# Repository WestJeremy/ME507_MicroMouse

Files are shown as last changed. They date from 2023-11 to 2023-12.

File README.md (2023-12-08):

# ME507_MicroMouse
This repository contains files for a custom PCB and c based code for a micromouse project for ME507 at Cal Poly SLO. This README.md file covers the task diagram and finite state implimentation used for this project.

## TASK DIAGRAM

## FINITE STATE MACHINES
### FloodFill Task
The following finite state machine is implimented for the task that impliments the floodfill algorithm for maze solving. The task begins in an idle state and begins maze solving once it recieves feedback from a start button. States 1-4 perform floodfill depending on the orientation of the micromouse. Micromouse competitions typically start with the robot in the top left corner facing towards the right. so this is what we designated state 1 to be. from there, once floodfill has been completed for a given cell the micromouse is oriented to the neighboring cell with the lowest manhatten distance and the state transitions accordingly.
State Diagrams-1

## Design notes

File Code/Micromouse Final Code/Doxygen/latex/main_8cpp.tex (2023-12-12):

\doxysection{C\+:/\+Users/westj/\+Micro\+Mouse/\+Code/\+Micromouse Final Code/src/main.cpp File Reference}
\hypertarget{main_8cpp}{}\label{main_8cpp}\index{C:/Users/westj/MicroMouse/Code/Micromouse Final Code/src/main.cpp@{C:/Users/westj/MicroMouse/Code/Micromouse Final Code/src/main.cpp}}

\doxylink{class_micromouse}{Micromouse} main application.  

{\ttfamily \#include $<$Arduino.\+h$>$}\newline
{\ttfamily \#include "{}Motor.\+h"{}}\newline
{\ttfamily \#include "{}States.\+h"{}}\newline
{\ttfamily \#include "{}Micromouse.\+h"{}}\newline
{\ttfamily \#include "{}MPU9250.\+h"{}}\newline
{\ttfamily \#include "{}Task\+\_\+\+Floodfill.\+h"{}}\newline
{\ttfamily \#include "{}Websocket\+Interface.\+h"{}}\newline
\doxysubsubsection*{Macros}
\begin{DoxyCompactItemize}
\item 
\Hypertarget{main_8cpp_a37976ee6fe1fb8546bfd6153b83ffa6c}\label{main_8cpp_a37976ee6fe1fb8546bfd6153b83ffa6c} 
\#define {\bfseries button}~34
\item 
\Hypertarget{main_8cpp_a37064104a00c75fbe3df57ca4f1d8040}\label{main_8cpp_a37064104a00c75fbe3df57ca4f1d8040} 
\#define {\bfseries PWM1\+\_\+pin}~14
\item 
\Hypertarget{main_8cpp_a56fb640fa36bbdcbdc3f2d2f22181bd1}\label{main_8cpp_a56fb640fa36bbdcbdc3f2d2f22181bd1} 
\#define {\bfseries AIN1\+\_\+pin}~15
\item 
\Hypertarget{main_8cpp_ab6ac800e89ce7f41548b83c3ece453c1}\label{main_8cpp_ab6ac800e89ce7f41548b83c3ece453c1} 
\#define {\bfseries AIN2\+\_\+pin}~32
\item 
\Hypertarget{main_8cpp_a73f29c0bd8f104a8da3cb7a14c479322}\label{main_8cpp_a73f29c0bd8f104a8da3cb7a14c479322} 
\#define {\bfseries ENCAPin}~21
\item 
\Hypertarget{main_8cpp_aea645f0b6f11181ae98fe927aa576bbd}\label{main_8cpp_aea645f0b6f11181ae98fe927aa576bbd} 
\#define {\bfseries ENCBPin}~4
\item 
\Hypertarget{main_8cpp_a068d3c0e64742cf567f12df1a87eb9bf}\label{main_8cpp_a068d3c0e64742cf567f12df1a87eb9bf} 
\#define {\bfseries PWM2\+\_\+pin}~12
\item 
\Hypertarget{main_8cpp_adca91662a86be44a53dbe26a16e65feb}\label{main_8cpp_adca91662a86be44a53dbe26a16e65feb} 
\#define {\bfseries BIN1\+\_\+pin}~33
\item 
\Hypertarget{main_8cpp_aa126243b01f040a93e00943699cfdc49}\label{main_8cpp_aa126243b01f040a93e00943699cfdc49} 
\#define {\bfseries BIN2\+\_\+pin}~27
\item 
\Hypertarget{main_8cpp_a226b03bf45d9fa491129fa48f5064210}\label{main_8cpp_a226b03bf45d9fa491129fa48f5064210} 
\#define {\bfseries ENC2\+APin}~25
\item 
\Hypertarget{main_8cpp_a3d09267bb6c6a9c43c6ece87795b945b}\label{main_8cpp_a3d09267bb6c6a9c43c6ece87795b945b} 
\#define {\bfseries ENC2\+BPin}~26
\item 
\Hypertarget{main_8cpp_a1aab17470a5d34c8aa1a2b76970dc6d6}\label{main_8cpp_a1aab17470a5d34c8aa1a2b76970dc6d6} 
\#define {\bfseries IR\+\_\+\+L\+\_\+\+Pin}~39
\item 
\Hypertarget{main_8cpp_a8a383679c8d33b11dbe82a661f0e10f6}\label{main_8cpp_a8a383679c8d33b11dbe82a661f0e10f6} 
\#define {\bfseries IR\+\_\+\+R\+\_\+\+Pin}~36
\end{DoxyCompactItemize}
\doxysubsubsection*{Functions}
\begin{DoxyCompactItemize}
\item 
\Hypertarget{main_8cpp_a0b7c7ebdb53540a4028a93e2dc0ee364}\label{main_8cpp_a0b7c7ebdb53540a4028a93e2dc0ee364} 
\mbox{\hyperlink{class_websocket_connection}{Websocket\+Connection}} {\bfseries Beep\+Boop\+Stream} (ssid, password, webpage,\&Mouse)
\item 
\Hypertarget{main_8cpp_a67469880db1a8b27f8bb719a2be58c18}\label{main_8cpp_a67469880db1a8b27f8bb719a2be58c18} 
void {\bfseries Encoder\+Update} ()
\begin{DoxyCompactList}\small\item\em Function to update both encoders. \end{DoxyCompactList}\item 
void \mbox{\hyperlink{main_8cpp_ae3665130cca18c36935037c1ba3a7396}{my\+Interrupt\+Task}} (void \texorpdfstring{$\ast$}{*}parameter)
\begin{DoxyCompactList}\small\item\em Task loop for encoder interrupt. \end{DoxyCompactList}\item 
void \mbox{\hyperlink{main_8cpp_abcebefd5a31e77dc51bda51c9da64e83}{button\+Interrupt\+Task}} (void \texorpdfstring{$\ast$}{*}parameter)
\begin{DoxyCompactList}\small\item\em Task loop for button interrupt. \end{DoxyCompactList}\item 
\Hypertarget{main_8cpp_a1cb72a248a56b5dc2b2ed27db7560b90}\label{main_8cpp_a1cb72a248a56b5dc2b2ed27db7560b90} 
void {\bfseries handle\+Interrupt} ()
\begin{DoxyCompactList}\small\item\em resume encoder task. \end{DoxyCompactList}\item 
\Hypertarget{main_8cpp_a73050f835725c0e7da1f5a23bddc3564}\label{main_8cpp_a73050f835725c0e7da1f5a23bddc3564} 
void {\bfseries handle\+Button\+Interrupt} ()
\begin{DoxyCompactList}\small\item\em resume button task. \end{DoxyCompactList}\item 
\Hypertarget{main_8cpp_a503ac9cf89b1c845bac770af86d49455}\label{main_8cpp_a503ac9cf89b1c845bac770af86d49455} 
void IRAM\+\_\+\+ATTR {\bfseries ISRH\+\_\+\+Handler\+\_\+button} ()
\begin{DoxyCompactList}\small\item\em ISR handler for button interrupt. \end{DoxyCompactList}\item 
\Hypertarget{main_8cpp_aed487527298b959af091ce104a03cd3a}\label{main_8cpp_aed487527298b959af091ce104a03cd3a} 
void IRAM\+\_\+\+ATTR {\bfseries ISRH\+\_\+\+Handler\+\_\+\+Encoder} ()
\begin{DoxyCompactList}\small\item\em ISR handler for encoder interrupt. \end{DoxyCompactList}\item 
\Hypertarget{main_8cpp_ae92caae85dbef22d6d338a986dbfb26e}\label{main_8cpp_ae92caae85dbef22d6d338a986dbfb26e} 
void {\bfseries Poll\+Sensors} ()
\begin{DoxyCompactList}\small\item\em Poll all sensors, and states and print to serial. \end{DoxyCompactList}\item 
\Hypertarget{main_8cpp_adeae6c2a7df392d037963ea8d7422340}\label{main_8cpp_adeae6c2a7df392d037963ea8d7422340} 
void {\bfseries Gotask} (void \texorpdfstring{$\ast$}{*}parameter)
\begin{DoxyCompactList}\small\item\em Main state system dispatcher for the microcmouse. \end{DoxyCompactList}\item 
\Hypertarget{main_8cpp_a8fd133b7047407a49ac8d08705641c99}\label{main_8cpp_a8fd133b7047407a49ac8d08705641c99} 
void {\bfseries setpostask} (void \texorpdfstring{$\ast$}{*}parameter)
\begin{DoxyCompactList}\small\item\em test software to set arbitrary goal position \end{DoxyCompactList}\item 
\Hypertarget{main_8cpp_a23c583ede08e583bb2a4fba0ac2abbf7}\label{main_8cpp_a23c583ede08e583bb2a4fba0ac2abbf7} 
void {\bfseries webservertask} (void \texorpdfstring{$\ast$}{*}parameter)
\begin{DoxyCompactList}\small\item\em task wrapper for webserver init \end{DoxyCompactList}\item 
\Hypertarget{main_8cpp_a4fc01d736fe50cf5b977f755b675f11d}\label{main_8cpp_a4fc01d736fe50cf5b977f755b675f11d} 
void {\bfseries setup} ()
\item 
\Hypertarget{main_8cpp_afe461d27b9c48d5921c00d521181f12f}\label{main_8cpp_afe461d27b9c48d5921c00d521181f12f} 
void {\bfseries loop} ()
\end{DoxyCompactItemize}
\doxysubsubsection*{Variables}
\begin{DoxyCompactItemize}
\item 
\Hypertarget{main_8cpp_a91ac39b56f805516fc9a5261b0682ba0}\label{main_8cpp_a91ac39b56f805516fc9a5261b0682ba0} 
int {\bfseries tof\+\_\+address} = 0x29
\item 
\Hypertarget{main_8cpp_a8401524759ad65a7d2cf99141ae1c5c3}\label{main_8cpp_a8401524759ad65a7d2cf99141ae1c5c3} 
volatile bool {\bfseries interrupt\+Flag} = false
\item 
\Hypertarget{main_8cpp_a8dae6ee4b13f5a7860eceb6099fa4ab1}\label{main_8cpp_a8dae6ee4b13f5a7860eceb6099fa4ab1} 
int {\bfseries cur\+\_\+state} =0
\item 
\Hypertarget{main_8cpp_aca139b9171377669a98ff02f0827e143}\label{main_8cpp_aca139b9171377669a98ff02f0827e143} 
int {\bfseries micromouse\+\_\+states} =2
\item 
\Hypertarget{main_8cpp_aad3afec3ae418e284c9e2530f0415bfc}\label{main_8cpp_aad3afec3ae418e284c9e2530f0415bfc} 
boolean {\bfseries x} =1
\item 
\Hypertarget{main_8cpp_a29716abd4f651ba9d6f1476ea79fa7ae}\label{main_8cpp_a29716abd4f651ba9d6f1476ea79fa7ae} 
uint8\+\_\+t {\bfseries pos} =0
\item 
\Hypertarget{main_8cpp_a72be9b640989f3d561a6bc8b67695eaa}\label{main_8cpp_a72be9b640989f3d561a6bc8b67695eaa} 
uint8\+\_\+t {\bfseries curpos} =0
\item 
\Hypertarget{main_8cpp_a05a1cfdf86c4b0267bb4800d588762cd}\label{main_8cpp_a05a1cfdf86c4b0267bb4800d588762cd} 
\mbox{\hyperlink{class_motor}{Motor}} {\bfseries motor1} (PWM1\+\_\+pin, AIN1\+\_\+pin, AIN2\+\_\+pin, ENCAPin, ENCBPin)
\item 
\Hypertarget{main_8cpp_a86fde6bfaf1528bef114dbf04ecb8906}\label{main_8cpp_a86fde6bfaf1528bef114dbf04ecb8906} 
\mbox{\hyperlink{class_motor}{Motor}} {\bfseries motor2} (PWM2\+\_\+pin, BIN1\+\_\+pin, BIN2\+\_\+pin, ENC2\+APin, ENC2\+BPin)
\item 
\Hypertarget{main_8cpp_a6bb3afab077d8caba2b6cb7122a6ec95}\label{main_8cpp_a6bb3afab077d8caba2b6cb7122a6ec95} 
\mbox{\hyperlink{class_i_r}{IR}} {\bfseries IR\+\_\+L} (IR\+\_\+\+L\+\_\+\+Pin)
\item 
\Hypertarget{main_8cpp_a0e017c1f2c3ec9a3ae8ab72c13b7d6a8}\label{main_8cpp_a0e017c1f2c3ec9a3ae8ab72c13b7d6a8} 
\mbox{\hyperlink{class_i_r}{IR}} {\bfseries IR\+\_\+R} (IR\+\_\+\+R\+\_\+\+Pin)
\item 
\Hypertarget{main_8cpp_ac9bba8b1da6565480f467cc137a83b03}\label{main_8cpp_ac9bba8b1da6565480f467cc137a83b03} 
\mbox{\hyperlink{class_time___of___flight}{Time\+\_\+\+Of\+\_\+\+Flight}} {\bfseries TOF} (tof\+\_\+address)
\item 
\Hypertarget{main_8cpp_a3ab266e6c650bec75f39cb48ce9b691e}\label{main_8cpp_a3ab266e6c650bec75f39cb48ce9b691e} 
\mbox{\hyperlink{class_m_p_u9250}{MPU9250}} {\bfseries IMU} (Wire, 0x68)
\item 
\Hypertarget{main_8cpp_a6e27f49150e9a14580fb313cc2777e00}\label{main_8cpp_a6e27f49150e9a14580fb313cc2777e00} 
int {\bfseries status}
\item 
\Hypertarget{main_8cpp_a697d6629110eed396003fdccae7e46b6}\label{main_8cpp_a697d6629110eed396003fdccae7e46b6} 
\mbox{\hyperlink{class_state}{State}} {\bfseries state} (micromouse\+\_\+states)
\item 
\Hypertarget{main_8cpp_a09d44a42942aaa9777f51d3a3e51c605}\label{main_8cpp_a09d44a42942aaa9777f51d3a3e51c605} 
\mbox{\hyperlink{class_solver}{Solver}} solve \& {\bfseries Mouse}
\item 
\Hypertarget{main_8cpp_a587ba0cb07f02913598610049a3bbb79}\label{main_8cpp_a587ba0cb07f02913598610049a3bbb79} 
const char \texorpdfstring{$\ast$}{*} {\bfseries ssid} = "{}Mojo\+Dojo\+Casa\+House"{}
\item 
\Hypertarget{main_8cpp_aa4a2ebcb494493f648ae1e6975672575}\label{main_8cpp_aa4a2ebcb494493f648ae1e6975672575} 
const char \texorpdfstring{$\ast$}{*} {\bfseries password} = "{}SUBLIME!"{}
\item 
\Hypertarget{main_8cpp_a0de2f6e0427579fab755bc06580de6fa}\label{main_8cpp_a0de2f6e0427579fab755bc06580de6fa} 
String {\bfseries webpage} = "{}$<$!DOCTYPE html$>$$<$html$>$$<$head$>$$<$title$>$Page Title$<$/title$>$$<$/head$>$$<$body style=\textquotesingle{}background-\/color\+: \#EEEEEE;\textquotesingle{}$>$$<$span style=\textquotesingle{}color\+: \#003366;\textquotesingle{}$>$$<$h1$>$\mbox{\hyperlink{class_micromouse}{Micromouse}} Websockets Interface$<$/h1$>$ $<$p$>$\mbox{\hyperlink{class_motor}{Motor}} 1 position\+: $<$span id=\textquotesingle{}rand1\textquotesingle{}$>$-\/$<$/span$>$$<$/p$>$$<$p$>$\mbox{\hyperlink{class_motor}{Motor}} 2 position\+: $<$span id=\textquotesingle{}rand2\textquotesingle{}$>$-\/$<$/span$>$$<$/p$>$$<$p$>$State\+: $<$span id=\textquotesingle{}state\textquotesingle{}$>$-\/$<$/span$>$$<$/p$>$$<$p$>$$<$button type=\textquotesingle{}button\textquotesingle{} id=\textquotesingle{}BTN\+\_\+\+SEND\+\_\+\+BACK\textquotesingle{}$>$Update \mbox{\hyperlink{class_state}{State}}$<$/button$>$$<$/p$>$$<$/span$>$$<$/body$>$$<$script$>$ var Socket; document.\+get\+Element\+By\+Id(\textquotesingle{}BTN\+\_\+\+SEND\+\_\+\+BACK\textquotesingle{}).add\+Event\+Listener(\textquotesingle{}click\textquotesingle{}, button\+\_\+send\+\_\+back); function init() \{ Socket = new Web\+Socket(\textquotesingle{}ws\+://\textquotesingle{} + window.\+location.\+hostname + \textquotesingle{}\+:81/\textquotesingle{}); Socket.\+onmessage = function(event) \{ process\+Command(event); \}; \} function button\+\_\+send\+\_\+back() \{ var msg = \{inc\+: 1,\};Socket.\+send(JSON.\+stringify(msg)); \} function process\+Command(event) \{var obj = JSON.\+parse(event.\+data);document.\+get\+Element\+By\+Id(\textquotesingle{}rand1\textquotesingle{}).inner\+HTML = obj.\+rand1;document.\+get\+Element\+By\+Id(\textquotesingle{}rand2\textquotesingle{}).inner\+HTML = obj.\+rand2; document.\+get\+Element\+By\+Id(\textquotesingle{}state\textquotesingle{}).inner\+HTML = obj.\+state; console.\+log(obj.\+rand1);console.\+log(obj.\+rand2); console.\+log(obj.\+state); \} window.\+onload = function(event) \{ init(); \}$<$/script$>$$<$/html$>$"{}
\item 
\Hypertarget{main_8cpp_a571995c6c0a4e5af7f20a7be285bdcd4}\label{main_8cpp_a571995c6c0a4e5af7f20a7be285bdcd4} 
Task\+Handle\+\_\+t {\bfseries my\+Int\+Task\+Handle} = NULL
\item 
\Hypertarget{main_8cpp_a462d8d6e871d6a221a5ec0d6da104913}\label{main_8cpp_a462d8d6e871d6a221a5ec0d6da104913} 
Task\+Handle\+\_\+t {\bfseries button\+Int\+Task\+Handle} = NULL
\item 
\Hypertarget{main_8cpp_a7c46df5b748e33e1c886fc8f1d74abc0}\label{main_8cpp_a7c46df5b748e33e1c886fc8f1d74abc0} 
port\+MUX\+\_\+\+TYPE {\bfseries mux} = port\+MUX\+\_\+\+INITIALIZER\+\_\+\+UNLOCKED
\end{DoxyCompactItemize}

\doxysubsection{Detailed Description}
\doxylink{class_micromouse}{Micromouse} main application. 

\begin{DoxyAuthor}{Author}
Jeremy West 
\end{DoxyAuthor}
\begin{DoxyDate}{Date}
2023-\/Nov-\/3 
\end{DoxyDate}

\doxysubsection{Function Documentation}
\Hypertarget{main_8cpp_abcebefd5a31e77dc51bda51c9da64e83}\label{main_8cpp_abcebefd5a31e77dc51bda51c9da64e83} 
\index{main.cpp@{main.cpp}!buttonInterruptTask@{buttonInterruptTask}}
\index{buttonInterruptTask@{buttonInterruptTask}!main.cpp@{main.cpp}}
\doxysubsubsection{\texorpdfstring{buttonInterruptTask()}{buttonInterruptTask()}}
{\footnotesize\ttfamily void button\+Interrupt\+Task (\begin{DoxyParamCaption}\item[{void \texorpdfstring{$\ast$}{*}}]{parameter }\end{DoxyParamCaption})}

Task loop for button interrupt. 

\begin{DoxyParams}{Parameters}
{\em parameter} & Task parameter (not used). \\
\hline
\end{DoxyParams}
\Hypertarget{main_8cpp_ae3665130cca18c36935037c1ba3a7396}\label{main_8cpp_ae3665130cca18c36935037c1ba3a7396} 
\index{main.cpp@{main.cpp}!myInterruptTask@{myInterruptTask}}
\index{myInterruptTask@{myInterruptTask}!main.cpp@{main.cpp}}
\doxysubsubsection{\texorpdfstring{myInterruptTask()}{myInterruptTask()}}
{\footnotesize\ttfamily void my\+Interrupt\+Task (\begin{DoxyParamCaption}\item[{void \texorpdfstring{$\ast$}{*}}]{parameter }\end{DoxyParamCaption})}

Task loop for encoder interrupt. 

\begin{DoxyParams}{Parameters}
{\em parameter} & Task parameter (not used). \\
\hline
\end{DoxyParams}

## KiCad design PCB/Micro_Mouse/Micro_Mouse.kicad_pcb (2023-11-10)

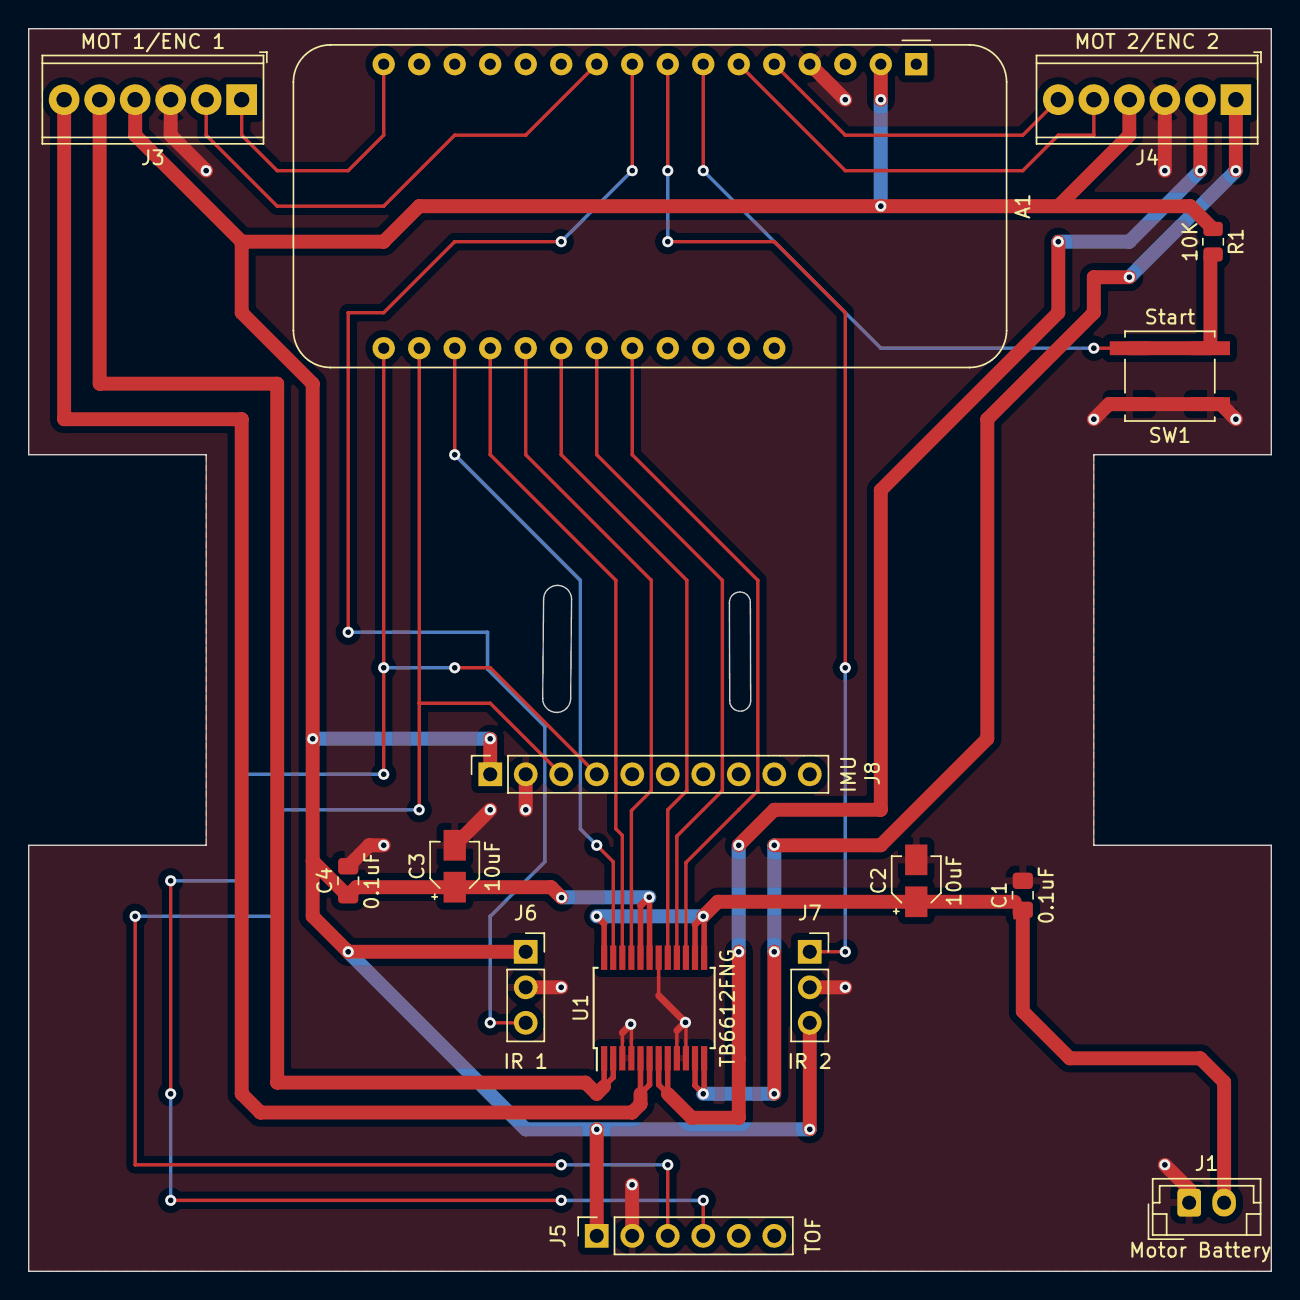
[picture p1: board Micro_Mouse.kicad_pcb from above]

Board: 2 copper layers, 88.9 x 88.9 mm, 15 parts (0 on the bottom side), 22 nets.

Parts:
A1: Adafruit_Feather_HUZZAH32_ESP32; Adafruit_Feather
C1, C4: 0.1uF; C_0805_2012Metric_Pad1.18x1.45mm_HandSolder
C2, C3: 10uF; CP_Elec_3x5.3
J1: Motor Battery; JST_EH_B2B-EH-A_1x02_P2.50mm_Vertical
J3: MOT 1/ENC 1; TerminalBlock_Phoenix_MPT-0,5-6-2.54_1x06_P2.54mm_Horizontal
J4: MOT 2/ENC 2; TerminalBlock_Phoenix_MPT-0,5-6-2.54_1x06_P2.54mm_Horizontal
J5: TOF; PinSocket_1x06_P2.54mm_Vertical
J6: IR 1; PinSocket_1x03_P2.54mm_Vertical
J7: IR 2; PinSocket_1x03_P2.54mm_Vertical
J8: IMU; PinSocket_1x10_P2.54mm_Vertical
R1: 10K; R_0805_2012Metric
SW1: Start; SW_Push_1P1T_NO_CK_KSC6xxJ
U1: TB6612FNG; SSOP-24_5.3x8.2mm_P0.65mm

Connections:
+3.3V: A1.2 (3V3), C3.1, C4.1, J3.4, J4.4, J5.1, J6.1, J7.3, J8.1, R1.1, U1.19 (STBY), U1.20 (VCC)
AIN1: A1.21 (A8/IO15), U1.21 (AIN1)
AIN2: A1.20 (A7/IO32), U1.22 (AIN2)
AO1: J3.5, U1.1 (AO1), U1.2 (AO1)
AO2: J3.6, U1.5 (AO2), U1.6 (AO2)
BIN1: A1.22 (A9/IO33), U1.17 (BIN1)
BIN2: A1.23 (A10/IO27), U1.16 (BIN2)
BO1: J4.1, U1.11 (BO1), U1.12 (BO1)
BO2: J4.2, U1.7 (BO2), U1.8 (BO2)
BTN: A1.7 (I34/A2), R1.2, SW1.1
E1_PHA: A1.10 (IO4/A5), J3.2
E1_PHB: A1.16 (IO21), J3.1
E2_PHA: A1.6 (DAC1/A1), J4.5
E2_PHB: A1.5 (DAC2/A0), J4.6
GND: A1.4 (GND), C1.2, C2.2, C3.2, C4.2, J1.1, J3.3, J4.3, J5.2, J6.2, J7.2, J8.2, SW1.2, U1.3 (PGND1), U1.4 (PGND1), U1.9 (PGND2), U1.10 (PGND2), U1.18 (GND)
I2C SCL: A1.18 (SCL/IO22), J5.3, J8.3
I2C SDA: A1.17 (SDA/IO23), J5.4, J8.4
IR_1: A1.9 (IO36/A4), J6.3
IR_2: A1.8 (I39/A3), J7.1
unnamed: C1.1, C2.1, J1.2, U1.13 (VM2), U1.14 (VM3), U1.24 (VM1)
PWMA: A1.19 (A6/IO14), U1.23 (PWMA)
PWMB: A1.24 (A11/IO12), U1.15 (PWMB)

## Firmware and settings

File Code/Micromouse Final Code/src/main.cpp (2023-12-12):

/**
 * @file main.cpp
 * @brief Micromouse main application.
 *  @author Jeremy West
 *  @date   2023-Nov-3
 */

#include <Arduino.h>
#include "Motor.h"
#include "States.h"
#include "Micromouse.h"
#include "MPU9250.h"
#include "Task_Floodfill.h"
#include "WebsocketInterface.h"


// Pin Setup
#define button 34

//motor 1
#define PWM1_pin 14
#define AIN1_pin 15
#define AIN2_pin 32

#define ENCAPin 21
#define ENCBPin 4

//motor 2
#define PWM2_pin 12
#define BIN1_pin 33
#define BIN2_pin 27

#define ENC2APin 25
#define ENC2BPin 26

//Sensors
#define IR_L_Pin 39
#define IR_R_Pin 36

int tof_address = 0x29;

// Global variable shared between ISR and task
volatile bool interruptFlag = false;

int cur_state=0;
int micromouse_states=2;

boolean x=1;
uint8_t pos=0;
uint8_t curpos=0;

//Object initilization
Motor motor1(PWM1_pin, AIN1_pin , AIN2_pin,ENCAPin, ENCBPin ); 
Motor motor2(PWM2_pin, BIN1_pin , BIN2_pin,ENC2APin, ENC2BPin );

IR IR_L(IR_L_Pin);
IR IR_R(IR_R_Pin);

Time_Of_Flight TOF(tof_address);

MPU9250 IMU(Wire, 0x68);
int status;





State state(micromouse_states);

Micromouse Mouse(&motor1, &motor2 , &IR_L , &IR_R , &TOF , &IMU, &state);

Solver solve(&Mouse);


// SSID and password of Wifi connection:
const char* ssid = "ID";
const char* password = "PASS";

// The String below "webpage" contains the complete HTML code that is sent to the client whenever someone connects to the webserver
String webpage = "<!DOCTYPE html><html><head><title>Page Title</title></head><body style='background-color: #EEEEEE;'><span style='color: #003366;'><h1>Micromouse Websockets Interface</h1> <p>Motor 1 position: <span id='rand1'>-</span></p><p>Motor 2 position: <span id='rand2'>-</span></p><p>State: <span id='state'>-</span></p><p><button type='button' id='BTN_SEND_BACK'>Update State</button></p></span></body><script> var Socket; document.getElementById('BTN_SEND_BACK').addEventListener('click', button_send_back); function init() { Socket = new WebSocket('ws://' + window.location.hostname + ':81/'); Socket.onmessage = function(event) { processCommand(event); }; } function button_send_back() { var msg = {inc: 1,};Socket.send(JSON.stringify(msg)); } function processCommand(event) {var obj = JSON.parse(event.data);document.getElementById('rand1').innerHTML = obj.rand1;document.getElementById('rand2').innerHTML = obj.rand2; document.getElementById('state').innerHTML = obj.state; console.log(obj.rand1);console.log(obj.rand2); console.log(obj.state); } window.onload = function(event) { init(); }</script></html>";
WebsocketConnection BeepBoopStream(ssid, password, webpage,&Mouse);

//Task Handles
TaskHandle_t myIntTaskHandle = NULL;
TaskHandle_t buttonIntTaskHandle = NULL;

// ___________________Functions___________________

/**
 * @brief Function to update both encoders.
 */
void EncoderUpdate(){

  Mouse.updateEncoder();
}

/**
 * @brief Task loop for encoder interrupt.
 * 
 * @param parameter Task parameter (not used).
 */
void myInterruptTask(void* parameter){
  //Task resumes on interrupt then suspends self
  for(;;){
    vTaskSuspend(NULL); //suspend self
    //Code to run on intterupt goes below
    EncoderUpdate();
   
  }
}

/**
 * @brief Task loop for button interrupt.
 * 
 * @param parameter Task parameter (not used).
 */
void buttonInterruptTask(void* parameter){
  //Task resumes on interrupt then suspends self
  for(;;){
    vTaskSuspend(NULL); //suspend self
    //Code to run on interupt goes below
    state.update();
    cur_state=state.get();

    //Serial.print(cur_state);
  }
}

/**
 * @brief resume encoder task.
 */
void handleInterrupt(){
  vTaskResume(myIntTaskHandle);
}

/**
 * @brief resume button task.
 */
void handleButtonInterrupt(){
  vTaskResume(buttonIntTaskHandle);
}

portMUX_TYPE mux = portMUX_INITIALIZER_UNLOCKED;


/**
 * @brief ISR handler for button interrupt.
 */
void IRAM_ATTR ISRH_Handler_button() {
    portENTER_CRITICAL_ISR(&mux);

    // Your ISR code here
    //handleButtonInterrupt();
    

    BaseType_t checkIfYieldRequired;
    checkIfYieldRequired = xTaskResumeFromISR(buttonIntTaskHandle);
    portYIELD_FROM_ISR(checkIfYieldRequired);

    portEXIT_CRITICAL_ISR(&mux);
}

/**
 * @brief ISR handler for encoder interrupt.
 */
void IRAM_ATTR ISRH_Handler_Encoder() {
    portENTER_CRITICAL_ISR(&mux);

    // Your ISR code here
    //EncoderUpdate();

    BaseType_t checkIfYieldRequired;
    checkIfYieldRequired = xTaskResumeFromISR(myIntTaskHandle);
    portYIELD_FROM_ISR(checkIfYieldRequired);

    portEXIT_CRITICAL_ISR(&mux);
}

/**
 * @brief Poll all sensors, and states and print to serial.
 */
void PollSensors(){

  Serial.print("Motor 1: ");
  Serial.print(motor1.encoderPosition);
  Serial.print("  ");

  Serial.print("Motor 2: ");
  Serial.print(motor2.encoderPosition);
  Serial.println("  ");

  Serial.print("State: ");
  Serial.println(cur_state);

  Serial.print("IR Left: ");
  Serial.print(IR_L.get());
  Serial.print("  ");
  Serial.print("IR Right: ");
  Serial.println(IR_R.get());
  
  Serial.print("TOF: ");
  Serial.println(TOF.get());

  Serial.print("IMU Z: ");
  IMU.readSensor();
  Serial.print("X:  ");
  Serial.print("  ");
  Serial.print(IMU.getMagX_uT(), 6);//roll 
  Serial.print("  ");
  Serial.print("Y:  ");
  Serial.print("  ");
  Serial.print(IMU.getMagY_uT(), 6);//yaw
  Serial.print("  ");
  Serial.print("Z:  ");
  Serial.println(IMU.getMagZ_uT(), 6);//pitch


  Serial.print("X:  ");
  Serial.print("  ");
  Serial.print(IMU.getGyroX_rads(), 6);
  Serial.print("  ");
  Serial.print("Y:  ");
  Serial.print("  ");
  Serial.print(IMU.getGyroY_rads(), 6);
  Serial.print("  ");
  Serial.print("Z:  ");
  Serial.print(IMU.getGyroZ_rads(), 6);

}

/**
 * @brief Main state system dispatcher for the microcmouse
 */
void Gotask(void* parameter){
  int Cells=1;
  int Moveops=2;
  Mouse.GoalAngle=0;
  State MoveState(Moveops);

  MoveState.update();

  
  for(;;){
  int cur_state=state.get();
  Serial.println(cur_state);


  if(cur_state >= 1){
    vTaskDelay(100);
    
    if (cur_state ==1){
      solve.task_floodfill();
      state.set(0);
    }

    if (cur_state ==2){
      PollSensors();
      
      //Serial.print("Started PID");

    }

  }else{
    Serial.print("  State Zero: Stand by -o-  ");
    motor1.stop();
    motor2.stop();
    vTaskDelay(500);
    
  }
  }
  vTaskDelay(10);
}




/**
 * @brief test software to set arbitrary goal position
 */
void setpostask(void* parameter){
  for(;;){
  int cur_state=state.get();
  if(cur_state == 1){
  motor1.setgoalpos(10000);
  motor2.setgoalpos(10000);
  motor1.stepsetposPID();
  motor2.stepsetposPID();
  }

  else{
    motor1.stop();
    motor2.stop();
    vTaskDelay(100);
    
  }
  }
}

/**
 * @brief task wrapper for webserver init
 */
void webservertask(void* parameter){
  BeepBoopStream.task();
}



//___________________Setup and Loop Functions___________________

void setup() {
  Serial.begin(115200);
  Serial.print("Starting");
  pinMode(button, INPUT);

  //Start Communication with TOF
  TOF.start();

  // start communication with IMU
  status = IMU.begin();
  if (status < 0) {
    Serial.println("IMU initialization unsuccessful");
    Serial.println("Check IMU wiring or try cycling power");
    Serial.print("Status: ");
    Serial.println(status);
    while (1) {}
  }

  Mouse.calIMU(); //calibrate IMU
  Mouse.zeroenc(); //Zero encoders

  //Start webserver
  BeepBoopStream.Start();

  //Encoder ISRs
  attachInterrupt(digitalPinToInterrupt(ENC2APin), ISRH_Handler_Encoder, CHANGE);
  attachInterrupt(digitalPinToInterrupt(ENC2BPin), ISRH_Handler_Encoder, CHANGE);
  attachInterrupt(digitalPinToInterrupt(ENCAPin), ISRH_Handler_Encoder, CHANGE);
  attachInterrupt(digitalPinToInterrupt(ENCBPin), ISRH_Handler_Encoder, CHANGE);

  //Button ISR for state control
  attachInterrupt(digitalPinToInterrupt(button), ISRH_Handler_button,RISING);
 

  //Tasks
  xTaskCreate (Gotask, "Go Task",  4096, NULL, 3, NULL);
  xTaskCreate (myInterruptTask, "Encoder ISR",  4096, NULL, 1, &myIntTaskHandle);
  xTaskCreate (buttonInterruptTask, "Button Interrupt",  4096, NULL, 2, &buttonIntTaskHandle);
  xTaskCreate (webservertask, "Webserver Task",  4096, NULL, 2, NULL);
}
 
void loop() {
  delay(1000);
  
}  

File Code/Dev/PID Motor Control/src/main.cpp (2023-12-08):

#include <Arduino.h>
#include "Motor.h"
//#include "FreeRTOS.h"
//#include "task.h"

 /*
  TB6612FNG-Dual-Driver
  made on 28 oct 2020
  by Amir Mohammad Shojaee @ Electropeak
  Adapted for esp32 feather by Jeremy West 2023
  Home
*/

// Pin Setup
#define button 34

//motor 1
#define PWM1_pin 14
#define AIN1_pin 15
#define AIN2_pin 32

#define ENCAPin 21
#define ENCBPin 4

//motor 2
#define PWM2_pin 12
#define BIN1_pin 33
#define BIN2_pin 27

#define ENC2APin 25
#define ENC2BPin 26

// Global variable shared between ISR and task
volatile bool interruptFlag = false;


boolean x=1;
uint8_t pos=0;
uint8_t curpos=0;


Motor motor1(PWM1_pin, AIN1_pin , AIN2_pin,ENCAPin, ENCBPin ); 
Motor motor2(PWM2_pin, BIN1_pin , BIN2_pin,ENC2APin, ENC2BPin );

//Task Handles
TaskHandle_t myIntTaskHandle = NULL;



// ___________________Functions___________________

void Baitandswitch(void* parameter){
  int speed=100;
 
  motor1.Movetest(speed);
  motor2.Movetest(speed+100);
}

//Encoder update loop 
void enc_loop(void* parameter){

  for(;;){

    motor1.updateEncoder();
    vTaskDelay(1);
  }
}

void bs(){
  //portENTER_CRITICAL_ISR(&mux);
  // Access or modify shared data
  interruptFlag = true;
  Serial.print(interruptFlag);
  motor1.updateEncoder();
  motor2.updateEncoder();
  interruptFlag = false;
  //taskEXIT_CRITICAL();
}

//Update Both Encoders
void EncoderUpdate(){
  motor1.updateEncoder();
  motor2.updateEncoder();
}


void myInterruptTask(void* parameter){

  for(;;){
    vTaskSuspend(NULL); //suspend self
    //Code to run on intterupt goes below
    EncoderUpdate();
   
  }
}


/* interrupt routine */
/* void ISRH_Handler(void){

  attachInterrupt(digitalPinToInterrupt(ENC2APin), handleInterrupt(), CHANGE);
  //HAL_GPIO_EXTI_IRQHandler(gpio13);
  BaseType_t checkIfYieldRequired;
  checkIfYieldRequired = xTaskResumeFromISR(myIntTaskHandle);
  portYIELD_FROM_ISR(checkIfYieldRequired);

} */

void handleInterrupt(){
  vTaskResume(myIntTaskHandle);
}

portMUX_TYPE mux = portMUX_INITIALIZER_UNLOCKED;

void IRAM_ATTR ISRH_Handler() {
  portENTER_CRITICAL_ISR(&mux);

  // Your ISR code here
  attachInterrupt(digitalPinToInterrupt(ENC2APin), handleInterrupt, CHANGE);

  BaseType_t checkIfYieldRequired;
  checkIfYieldRequired = xTaskResumeFromISR(myIntTaskHandle);
  portYIELD_FROM_ISR(checkIfYieldRequired);

  portEXIT_CRITICAL_ISR(&mux);
}

void IRAM_ATTR ISRH_HandlerGPT() {
    portENTER_CRITICAL_ISR(&mux);

    // Your ISR code here
    
    EncoderUpdate();

    BaseType_t checkIfYieldRequired;
    checkIfYieldRequired = xTaskResumeFromISR(myIntTaskHandle);
    portYIELD_FROM_ISR(checkIfYieldRequired);

    portEXIT_CRITICAL_ISR(&mux);
}

void PollEnc(void* parameter){
for(;;){
  Serial.println(motor1.encoderPosition);
  Serial.println(motor2.encoderPosition);
  vTaskDelay(1000);

}
}

//Encoder update loop 
void enc_loop2(void* parameter){

  attachInterrupt(ENCAPin, bs, CHANGE);
  attachInterrupt(ENCBPin, bs, CHANGE);

  for(;;){
    vTaskDelay(1000);
  }
}

void setpostask(void* parameter){
  
  //motor1.goalpos=100;
  //motor1.setpos(100,60);
  motor1.setgoalpos(100);
  motor1.setposPID();

}

void but_task(void* parameter){
  for(;;){
    while(interruptFlag==true){
      vTaskDelay(10);
    }

    ( digitalRead(button) == HIGH) ?  motor1.move(100): motor1.move(200);

    vTaskDelay(10);
  }


}


//___________________Setup and Loop Functions___________________

void setup() {
  Serial.begin(115200);
  Serial.print("Starting");
  pinMode(button, INPUT);

  attachInterrupt(digitalPinToInterrupt(ENC2APin), ISRH_HandlerGPT, CHANGE);
  attachInterrupt(digitalPinToInterrupt(ENC2BPin), ISRH_HandlerGPT, CHANGE);
  attachInterrupt(digitalPinToInterrupt(ENCAPin), ISRH_HandlerGPT, CHANGE);
  attachInterrupt(digitalPinToInterrupt(ENCBPin), ISRH_HandlerGPT, CHANGE);
/*   attachInterrupt(ENCAPin, bs, CHANGE);
  attachInterrupt(ENCBPin, bs, CHANGE);

  attachInterrupt(ENC2APin, bs, CHANGE); 
  attachInterrupt(ENC2BPin, bs, CHANGE); */

  //motor1.move(100);
  //boolean E = motor1.getenc();
  //Serial.print(E);
  //xTaskCreate (Baitandswitch, "A",  4096, NULL, 1, NULL);
  //xTaskCreate (enc_loop, "ENC",  4096, NULL, 2, NULL);
  xTaskCreate (setpostask, "setpos",  4096, NULL, 1, NULL);
  xTaskCreate (PollEnc, "Hope",  4096, NULL, 1, NULL);
  //xTaskCreate (but_task, "move",  4096, NULL, 1, NULL);
  xTaskCreate (myInterruptTask, "Interrupt",  4096, NULL, 1, &myIntTaskHandle);

  //vTaskStartScheduler();
  
  //motor1.move(100);
  //motor2.move(200);

}
 
void loop() {
  delay(1000);
  
}  

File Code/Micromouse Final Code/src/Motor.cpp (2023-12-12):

/** 
 * @file Motor.cpp
 * @brief Implementation of the Motor class.
 * 
 *  @author Jeremy West
 *  @date   2023-Oct-10
 * 
 */


#include "Motor.h"

/**
 * @brief Constructor for the Motor class.
 * 
 * @param pwmPin PWM pin for motor speed control.
 * @param dirPin1 Direction pin 1.
 * @param dirPin2 Direction pin 2.
 * @param encA1Pin Encoder channel A1 pin.
 * @param encA2Pin Encoder channel A2 pin.
 */
Motor::Motor(int pwmPin, int dirPin1, int dirPin2,int encA1Pin,int encA2Pin) : pwmPin_(pwmPin), dirPin1_(dirPin1), dirPin2_(dirPin2), encA1Pin_(encA1Pin), encA2Pin_(encA2Pin){
    pinMode(pwmPin_, OUTPUT);
    pinMode(dirPin1_, OUTPUT);
    pinMode(dirPin2_, OUTPUT);
    pinMode(encA1Pin_, INPUT);
    pinMode(encA2Pin_, INPUT);
    //pinMode(encA2_Pin, INPUT);
    analogWrite(pwmPin_, 0);  // Initialize PWM with 0% duty cycle
}


/**
 * @brief Update the motor encoder position.
 */
void Motor:: updateEncoder() {
    //Print statements in this function will crash the microcontroller due to ISR so dont do that
        int8_t shaft_angle = 0.0;
        int MSB = digitalRead(encA1Pin_);
        int LSB = digitalRead(encA2Pin_);

        int encoded = (MSB << 1) | LSB;
        int sum = (lastEncoded << 2) | encoded;

        if (sum == 0b1101 || sum == 0b0100 || sum == 0b0010 || sum == 0b1011) {
            encoderPosition-- ;
        } else if (sum == 0b1110 || sum == 0b0111 || sum == 0b0001 || sum == 0b1000) {
            encoderPosition++ ;
        }

        lastEncoded = encoded;
}

/**
 * @brief Zero the motor encoder position.
 */
void Motor::zeroEncPos(){
    int zero=0;
    encoderPosition=zero;
} 


/**
 * @brief Move the motor at a specified speed.
 * 
 * @param speed Speed of the motor.
 */
void Motor::move(int speed) {
    boolean dir=(speed >= 0) ? 1 : 0; //if speed in negative set dir in reverse
    uint8_t abs_speed = speed;
    digitalWrite(dirPin1_, dir);
    digitalWrite(dirPin2_, !dir);
    analogWrite(pwmPin_, abs_speed);  // Set the PWM duty cycle (0-255)

}

/**
 * @brief Move the motor at a specified speed and direction.
 * 
 * @param speed Speed of the motor.
 * @param dir Direction of the motor.
 */
void Motor::move(int speed,boolean dir) {
    digitalWrite(dirPin1_, dir);
    digitalWrite(dirPin2_, !dir);
    analogWrite(pwmPin_, speed);  // Set the PWM duty cycle (0-255)
    vTaskDelay(10);
}

/**
 * @brief Set the goal position for the motor in encoder counts.
 * 
 * @param pos The goal position.
 */
void Motor:: setgoalpos(int pos) {
goalpos=pos;
}

/**
 * @brief Move the motor to a specified position with a specified speed.
 * 
 * @param goalpos The goal position.
 * @param speed Speed of the motor.
 */
void Motor::setpos(int goalpos, int speed) {
    boolean dirt=1;
    for(;;){
        updateEncoder();
        if (goalpos>encoderPosition){
            dirt=1;
        } else if(goalpos<encoderPosition){
            dirt=0;
        }
        move(speed,dirt);
        vTaskDelay(1);
        Serial.println(encoderPosition);
    }
}

/**
 * @brief Move the motor to a specified position using PID control.
 */
void Motor::setposPID() {

    int t_step=10;

    int error=goalpos-encoderPosition;
    float pre_error=0;
    float I_error=0;
    float dt_error=0;
    float d_error;

    int p_in;
    int i_in;
    int d_in;

    float kp = 1;
    float ki=0.01;
    float kd=0.01;

    float t_in;

    for(;;){

        error=goalpos-encoderPosition;
        I_error=I_error+error;
        d_error=error-pre_error/t_step;

        p_in=error*kp;
        i_in=I_error*ki;
        d_in=-d_error*kd;

        t_in=p_in+i_in+d_in;
        t_in=(t_in > 255) ? 255 : t_in; //if the controler input is oversaturated write it to 100%
        move(t_in);

        vTaskDelay(t_step);
    }
}

/**
 * @brief Test function for moving the motor forward and backward.
 * 
 * @param speed Speed of the motor.
 */
void Motor::Movetest(int speed) {
    move(speed);
    for(;;){
        move(speed);

        
        vTaskDelay(1000);
        move(-speed*2); 
        vTaskDelay(2000); 

    }
}

/**
 * @brief Perform a stepwise movement to a specified position using PID control.
 */
void Motor::stepsetposPID() {

    int t_step=10;

    int error=goalpos-encoderPosition;
    float pre_error=0;
    float I_error=0;
    float dt_error=0;
    float d_error;

    int p_in;
    int i_in;
    int d_in;

    float kp = 1;
    float ki=0.01;
    float kd=0.01;

    float t_in;

    

        error=goalpos-encoderPosition;
        I_error=I_error+error;
        d_error=error-pre_error/t_step;

        p_in=error*kp;
        i_in=I_error*ki;
        d_in=-d_error*kd;

        t_in=p_in+i_in+d_in;
        t_in=(t_in > 255) ? 255 : t_in; //if the controler input is oversaturated write it to 100%
        move(t_in);

        vTaskDelay(t_step);
    
}

/**
 * @brief Perform a stepwise movement to a specified position using PID control.
 * 
 * @param error Error value.
 */
void Motor::stepsetposPID(float error) {

    int t_step=10;


    float pre_error=0;
    float I_error=0;
    float dt_error=0;
    float d_error;

    int p_in;
    int i_in;
    int d_in;

    float kp = 1;
    float ki=0.01;
    float kd=0.01;

    float t_in;

    

        error=goalpos-encoderPosition;
        I_error=I_error+error;
        d_error=error-pre_error/t_step;

        p_in=error*kp;
        i_in=I_error*ki;
        d_in=-d_error*kd;

        t_in=p_in+i_in+d_in;
        t_in=(t_in > 255) ? 255 : t_in; //if the controler input is oversaturated write it to 100%
        move(t_in);

        vTaskDelay(t_step);
    
}

/**
 * @brief Perform a stepwise movement to a specified position using PID control.
 * 
 * @param U Control input.
 */
void Motor::stepsetposPIDU(float U) {
    int t_step=10;

    float pre_error=0;
    float I_error=0;
    float dt_error=0;
    float d_error=0;

    int p_in=0;
    int i_in=0;
    int d_in=0;

    float kp = 1;
    float ki=0.01;
    float kd=0.01;

    float t_in;

    //float error=goalpos-encoderPosition+U;

    float error=goalpos-encoderPosition;

    //float error=U;
    I_error=I_error+error;
    d_error=error-pre_error/t_step;

    p_in=error*kp;
    i_in=I_error*ki;
    d_in=-d_error*kd;

    t_in=p_in+i_in+d_in;
    float tu=kp*U;//+ki*U+kd*U;

/*     Serial.print("pos: ");
    Serial.print(p_in+i_in+d_in);
    Serial.print("      ");
 */
 

    t_in=(t_in > 200) ? 200 : t_in; //if the controler input is oversaturated write it to 100%
    t_in=t_in+tu;
    t_in=(t_in > 255) ? 255 : t_in; //if the controler input is oversaturated write it to 100%
    move(t_in);
    //Serial.print("t_in: ");
    //Serial.println(t_in);

    vTaskDelay(t_step);
}

/**
 * @brief Perform a a move forward at a constant speed
 * 
 * @param speed speed 0-255.
 */
void Motor::forward(int speed) {
    digitalWrite(dirPin1_, HIGH);
    digitalWrite(dirPin2_, LOW);
    analogWrite(pwmPin_, speed);  // Use analogWrite to set the PWM duty cycle (0-1023)
}
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

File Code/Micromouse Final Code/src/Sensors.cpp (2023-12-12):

/** 
 * @file Sensors.cpp
 * @brief Implementation of the Sensors class.
 *  @author Jeremy West
 *  @date   2023-Nov-10
 */

#include "Sensors.h"

/**
 * @brief Constructor for the IR class.
 * 
 * @param pin The pin connected to the IR sensor.
 */
IR::IR(int pin):pin_(pin){
    pinMode(pin, INPUT);
}

/**
 * @brief Get the status of the IR sensor.
 * 
 * @return True if an object is detected, false otherwise.
 */
boolean IR::get() {
    //read if object detected 1 yes 0 no
    return(!digitalRead(pin_));
}

/**
 * @brief Constructor for the Time_Of_Flight class.
 * 
 * @param address The I2C address of the TOF sensor.
 */
Time_Of_Flight::Time_Of_Flight(int address): address_(address){
    Serial.println("here we go...");

}


/**
 * @brief Initialize the TOF sensor.
 */
void Time_Of_Flight::start(){
// wait until serial port opens for native USB devices
  while (! Serial) {
    delay(1);
  }


  Serial.println("Adafruit VL53L0X test");
  if (!lox.begin(address_)) {
    Serial.println(F("Failed to boot VL53L0X"));
    while(1);
  }
  // power 
  Serial.println(F("VL53L0X API Simple Ranging example\n\n")); 
}

/**
 * @brief Get the distance measured by the TOF sensor.
 * 
 * @return The distance in millimeters.
 */
float Time_Of_Flight::get() {
  //for TOF sensor https://electronoobs.com/eng_arduino_tut73.php
  VL53L0X_RangingMeasurementData_t measure;
    
  lox.rangingTest(&measure, false); // pass in 'true' to get debug data printout!

  if (measure.RangeStatus != 4) {  // phase failures have incorrect data
    dist=measure.RangeMilliMeter;
  } else {
    Serial.println(" out of range ");
    dist=8000;
  }

    return dist;
}

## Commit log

2023-11-18 Continued Improvement and debugging of PID control
2023-11-23 Add files via upload
    contains floodfill and sensor task
